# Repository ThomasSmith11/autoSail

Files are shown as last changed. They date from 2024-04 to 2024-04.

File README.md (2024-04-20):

# Autonomous Sailing System

## Overview
This project is aimed at developing an autonomous sailboat navigation system using Arduino and Python. The system enables the boat to navigate along a path of set waypoints autonomously.  Those waypoints can be selected graphically with a python app and uploaded to the vessel prior to launch.

## Components I Used
- **RC Laser**: https://rclaser.org/
  
- **Sail Winch Servo**: [https://www.amazon.com/Hitec-RCD-33785S-HS-785HB-Winch](https://www.amazon.com/Hitec-RCD-33785S-HS-785HB-Winch/dp/B000BOGI7E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)

- **Wind Direction Sensor**: [https://www.amazon.com/Direction-Sensor-Supply-Voltage-Output](https://www.amazon.com/Direction-Sensor-Supply-Voltage-Output/dp/B07GP154HP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)

- **GPS Sensor**: [https://www.amazon.com/Navigation-Positioning-Microcontroller-Compatible-Sensitivity](https://www.amazon.com/Navigation-Positioning-Microcontroller-Compatible-Sensitivity/dp/B0B31NRSD2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)

## Dependencies
- **Arduino IDE**: Required to upload the Arduino code to the microcontroller onboard the boat.
  
- **Python**: The Python application requires Python installed on the user's system. It also depends on several libraries present in Coordinate_Plotter/requirements.txt.

## Installation
1. Clone the repository to your local machine.
`git clone https://github.com/ThomasSmith11/autoSail.git`

2. Upload the Arduino code (`autoSail.ino`) to your Arduino board using the Arduino IDE.

3. Install the required Python dependencies.
`pip install Coordinate_Plotter/requirements.txt`

## Usage
1. Replace sail winch servo with purchased one, and install 3d printed wind direction sensor mount (found [here](Supplementary_Files)) on the bow of the boat.

2. Connect the Arduino board to your boat's hardware using the wiring diagram [here](Supplementary_Files/autoSailWiring.png).

3. Ensure that the boat is powered on.

4. Launch the Python application by running `python3 Coordinate_Plotter/gpsPlotter.py` and connect the arduino via USB.

5. Follow the on-screen instructions to select waypoints and send them to the boat.

6. Launch the boat, navigate to a safe location, then switch from manual control to autonomous control by pushing the left stick all the way to the right. You may regain manual control at any time by pushing the stick all the way to the left.

## License
This project is licensed under the MIT [License](LICENSE)

## Acknowledgments
- Special thanks to [@paulienov](https://github.com/paulienov) for helping design, troubleshoot, and debug the whole system as well as for printing the sensor mount.

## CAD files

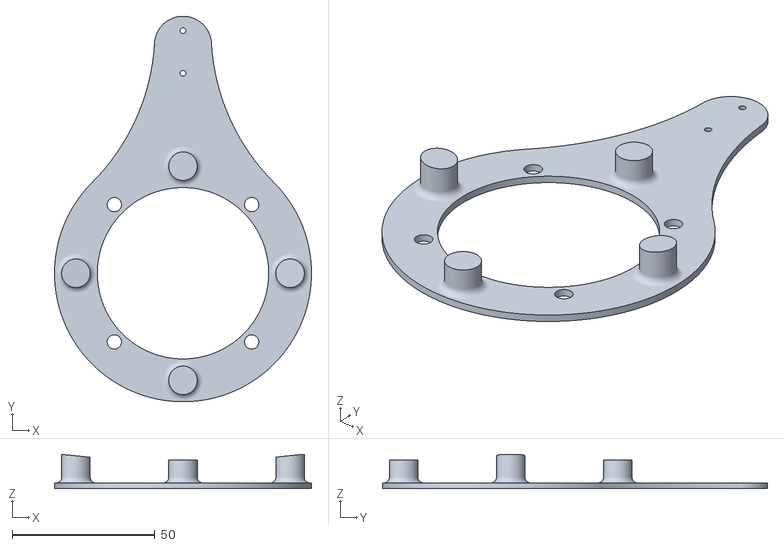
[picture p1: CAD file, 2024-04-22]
Supplementary_Files/RCLaserWindSensorMount_V3.stl
90.0 x 135.0 x 12.0

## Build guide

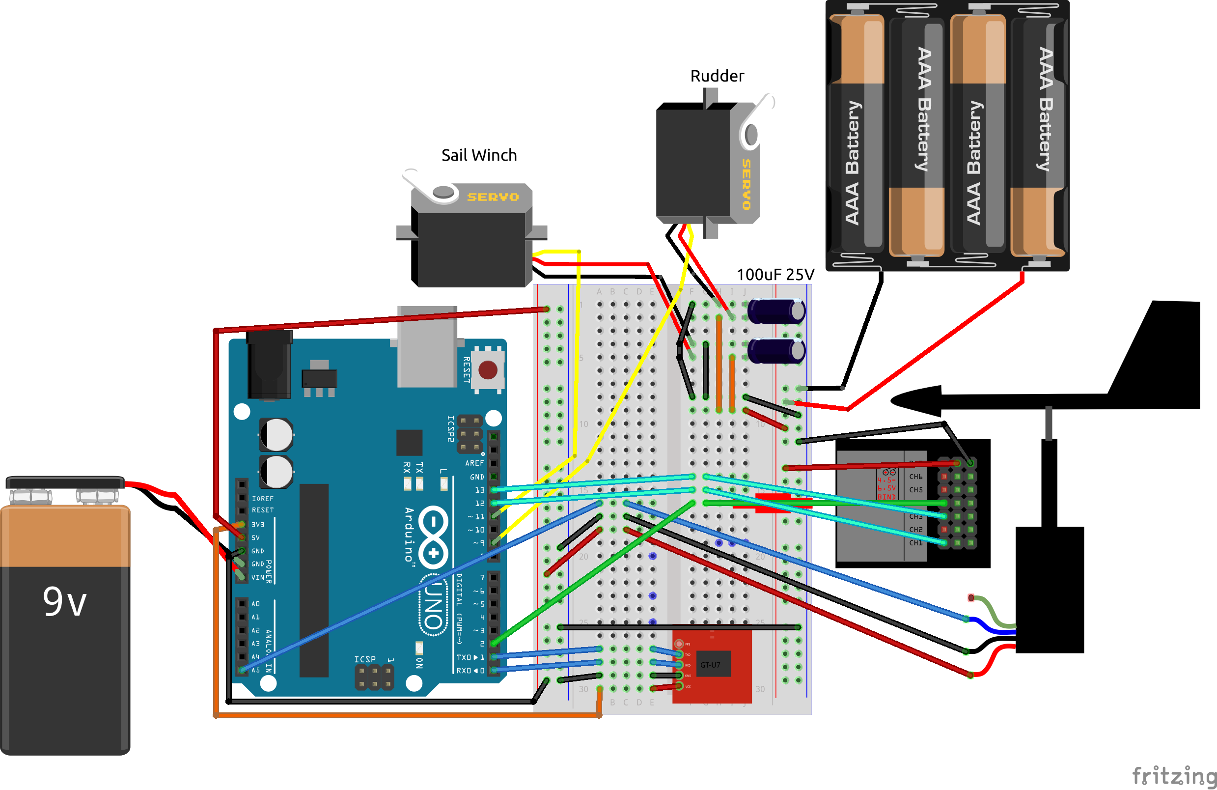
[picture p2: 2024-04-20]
Supplementary_Files/autoSailWiring.png

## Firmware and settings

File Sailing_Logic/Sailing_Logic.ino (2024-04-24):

#include <Servo.h>
#include <TinyGPS++.h>
#include <SoftwareSerial.h>

struct GPSCoordinate {
  float latitude;
  float longitude;
};

static const int controlPin = 2;
static const int gpsControlPin = 4;
static const int rudderOutputPin = 9;
static const int mainsheetOutputPin = 11;
static const int rudderPin = 12;
static const int mainsheetPin = 13;
static const int windSensorPin = A5;
static const uint32_t GPSBaud = 9600;
unsigned long time = 1400;

unsigned long waveStart;
unsigned long waveEnd;



Servo rudder;
Servo mainsheet;
TinyGPSPlus gps;


int prevIndex, destIndex;
GPSCoordinate prevCoords, currCoords, destCoords;


// Sensor inputs
int windSensorValue, mainsheetValue, rudderValue;


int windDirection;
int mainsheetTrim;
int rudderPosition;
float destHeading;
int currentHeading;
int targHeading;
float velocity;
float distanceOffLine;

char inData[26];
int numCoords = 0;
GPSCoordinate coordinates[32];


volatile bool manualControl = 1;
bool temp;
//May need to be switched


void setup() {
  Serial.begin(115200);
  Serial.println("Ready\n");
  while (true) {
    int index = 0;
    while (true) {
      if (Serial.available() > 0) {
        char c = Serial.read();
        if (c == '\n') {
          inData[index++] = '\0';
          break;
        } else {
          inData[index++] = c;
        }
      }
    }
    
    if (strcmp(inData, "␄") == 0) {
      break;
    }
    
    coordinates[numCoords++] = parseCoordinateString(inData);
  }
  attachInterrupt(digitalPinToInterrupt(controlPin), handleInterrupt, CHANGE);
  //audible ten second countdown before turning on gps and beginning loop
  for (int i = 0; i<10; i++) {
    blockingTone(7, 2000, 500);
    blockingTone(7, 0, 500);
  }
  Serial.begin(GPSBaud);
  pinMode(gpsControlPin, OUTPUT);
  digitalWrite(gpsControlPin, HIGH); // turn gps on
  pinMode(controlPin, INPUT);
  pinMode(rudderPin, INPUT);
  pinMode(mainsheetPin, INPUT);
  rudder.attach(rudderOutputPin);
  mainsheet.attach(mainsheetOutputPin);
}


void loop() {
  if (manualControl) {
    mainsheetValue = pulseIn(mainsheetPin, HIGH);
    rudderValue = pulseIn(rudderPin, HIGH);
    mainsheet.writeMicroseconds(mainsheetValue);
    rudder.writeMicroseconds(rudderValue);
  }
  else {
    finishedWaypoints:
    if (destIndex >= numCoords) {
      rudder.writeMicroseconds(1750);
    }
    while (Serial.available() > 0)
      if (gps.encode(Serial.read()))
        processGPS();

    if (prevIndex == NULL) {
      prevIndex = -1;
      destIndex = 0;
      prevCoords = currCoords;
      destCoords = coordinates[destIndex];
    }

    if (TinyGPSPlus::distanceBetween(currCoords.latitude, currCoords.longitude, destCoords.latitude, destCoords.longitude) < 3) {
      prevIndex++;
      destIndex++;
      if (destIndex >= numCoords) {
        goto finishedWaypoints;
      }
      destCoords = coordinates[destIndex];
      prevCoords = coordinates[prevIndex];
    }

    windSensorValue = analogRead(windSensorPin);
    Serial.println(windSensorValue);
    windDirection = map(windSensorValue, 0,1006, 0, 359);
    Serial.println(windDirection);
    mainsheetTrim = calculateSailAngle(windDirection);
    mainsheet.writeMicroseconds(mainsheetTrim);

    float destHeading = TinyGPSPlus::courseTo(currCoords.latitude, currCoords.longitude, prevCoords.latitude, prevCoords.longitude);

    distanceOffLine = calculateDistanceOffLine(destHeading, currCoords, prevCoords);
    bool toRightOfLine = determineSideofLine(destCoords, currCoords, prevCoords);
    targHeading = calculateTargetHeading(destHeading, currentHeading, windDirection, distanceOffLine, toRightOfLine);
    rudderPosition = calculateRudderPosition(currentHeading, targHeading);
    rudder.writeMicroseconds(rudderPosition);
  }
}


GPSCoordinate parseCoordinateString(char* gpsString) {
  GPSCoordinate coord;
  char *lat_str = strtok(gpsString, ",");
  char *lon_str = strtok(NULL, ",");
  if (lat_str != NULL && lon_str != NULL) {
    float lat = atof(lat_str);
    float lon = atof(lon_str);
    coord = {lat, lon};
  }
  return coord;
}


int calculateSailAngle(int windDirection) {
  int sailAngle;
  windDirection -= 180;
  windDirection = abs(windDirection);
  if (windDirection < 45) {
    sailAngle = 1750;
  }
  else {
    sailAngle = map(windDirection, 45, 180, 1750, 1150);
  }
  return sailAngle;
}


void processGPS() {
  if (gps.location.isValid())
  {
    currCoords.latitude = gps.location.lat();
    currCoords.longitude = gps.location.lng();
    currentHeading = int(gps.course.deg()+.5);
    // velocity = gps.speed.knots();
  }
}

void handleInterrupt(){
  int value = digitalRead(controlPin);
  if (value == 1) {
    waveStart = micros();
  }
  else {
    waveEnd = micros();
    time = waveEnd - waveStart;
  }
  if(time<1250){
    manualControl = 1;
  }
  if(time>1800){
    manualControl = 0;
  }
}


float calculateDistanceOffLine(float destHeading, GPSCoordinate current, GPSCoordinate previous) {
  float currLat = current.latitude;
  float currLon = current.longitude;
  float prevLat = previous.latitude;
  float prevLon = previous.longitude;

  float headingFromPrevToCurrent = TinyGPSPlus::courseTo(prevLat, prevLon, currLat, currLon);
  float distanceFromPrevToCurrent = TinyGPSPlus::distanceBetween(prevLat, prevLon, currLat, currLon);
  float theta = radians(headingFromPrevToCurrent - destHeading);
  return distanceFromPrevToCurrent * sin(theta);
}


bool determineSideofLine(GPSCoordinate destination, GPSCoordinate current, GPSCoordinate previous) {
  float Ax = destination.latitude - previous.latitude;
  float Ay = destination.longitude - previous.longitude;
  float Bx = current.latitude - previous.latitude;
  float By = current.longitude - previous.longitude;

  float crossProduct = Ax * By - Bx * Ay;

  if (crossProduct > 0) {
    return 1;
  } else {
    return 0;
  }
}


int calculateRudderPosition(int currentHeading, int targHeading) {
  int rudderScale;
  
  int clockwiseDiff = (targHeading - currentHeading + 360) % 360;
  int counterclockwiseDiff = (currentHeading - targHeading + 360) % 360;
  if (clockwiseDiff < counterclockwiseDiff) {
      rudderScale = calcRudderScale(abs(targHeading-currentHeading));
  } else {
      rudderScale = calcRudderScale(abs(targHeading-currentHeading))*-1;
  }

  return rudderScale+1515;
}


int calcRudderScale(int headingDiff) {

// change rudder scale in 8 degree increments, such that above ~40 degrees off course we get maximum steering,
// then smoother steering as we approach the correct course.  Max rudder scale should be 6, min -6

  if (headingDiff >= 60) {
    return 400;
  }
  else {
    return map(headingDiff, 0, 59, 0, 400);
  }
}


int calculateTargetHeading(float destHeading, int currentHeading, int windDirection, float distanceAway, bool toRightOfLine) {
  int actualWindDirection = (windDirection+currentHeading)%360;
  if (abs(actualWindDirection-destHeading) > 40) {
    return int(destHeading+.5); //round destHeading to nearest whole number
  }
  else {
    if (distanceAway < 3) {
      int clockwiseDiff = (actualWindDirection - currentHeading + 360) % 360;
      int counterclockwiseDiff = (currentHeading - actualWindDirection + 360) % 360;
      bool starboard = (clockwiseDiff<counterclockwiseDiff);
      if (starboard) {
        return (actualWindDirection + 320) % 360;
      }
      else {
        return (actualWindDirection + 40) % 360;
      }
    }
    else {
      if (toRightOfLine) {
        return (actualWindDirection + 320) % 360;
      }
      else {
        return (actualWindDirection + 40) % 360;
      }
    }
  }
}


void blockingTone(uint8_t pin, unsigned int frequency, unsigned long duration) {
    pinMode(pin, OUTPUT);
    unsigned long startTime = micros();

    while (micros() - startTime < duration * 1000) {
        unsigned long currentTime = micros() - startTime;
        if (currentTime % (1000000 / frequency) < (1000000 / (2 * frequency))) {
            digitalWrite(pin, HIGH);
        } else {
            digitalWrite(pin, LOW);
        }
    }

    digitalWrite(pin, LOW);
}

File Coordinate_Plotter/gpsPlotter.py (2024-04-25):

import time
import serial
import tkinter
import customtkinter
import serial.tools.list_ports
from tkintermapview import TkinterMapView
from tkintermapview.canvas_position_marker import CanvasPositionMarker

customtkinter.set_default_color_theme("dark-blue")

class CustomWaypointMarker(CanvasPositionMarker):
    def __init__(self, *args, **kwargs):
        super().__init__(*args, **kwargs)
        self.text_color = "#C5542D"

class CustomMapView(TkinterMapView):
    
    def __init__(self, app, *args, **kwargs):
        super().__init__(*args, **kwargs)
        self.app = app
        self.tile_server = "https://mt0.google.com/vt/lyrs=s&hl=en&x={x}&y={y}&z={z}&s=Ga"
    
    def mouse_right_click(self, event):
        coordinate_mouse_pos = self.convert_canvas_coords_to_decimal_coords(event.x, event.y)

        def click_coordinates_event():
            try:
                self.set_marker(coordinate_mouse_pos[0], coordinate_mouse_pos[1], text=(str(len(app.waypointList)+1)))
                app.update_waypoints_listbox()

            except Exception as err:
                tkinter.messagebox.showinfo(title="", message="Error adding waypoint to course: \n" + str(err))

        m = tkinter.Menu(self, tearoff=0)
        m.add_command(label=f"Add Waypoint", command=click_coordinates_event)

        m.tk_popup(event.x_root, event.y_root)
    
    def set_marker(self, deg_x: float, deg_y: float, text: str = None, **kwargs) -> CustomWaypointMarker:
        marker = CustomWaypointMarker(self, (deg_x, deg_y), text=text, **kwargs)
        marker.draw()
        self.canvas_marker_list.append(marker)
        return marker


class App(customtkinter.CTk):

    APP_NAME = "AutoSail GPS Plotter"
    WIDTH = 1400
    HEIGHT = 800

    def __init__(self, *args, **kwargs):
        super().__init__(*args, **kwargs)
        customtkinter.set_appearance_mode("dark")
        self.title(App.APP_NAME)
        self.geometry(str(App.WIDTH) + "x" + str(App.HEIGHT))
        self.minsize(App.WIDTH, App.HEIGHT)

        self.protocol("WM_DELETE_WINDOW", self.on_closing)
        self.bind("<Control-q>", self.on_closing)
        self.bind("<Control-w>", self.on_closing)

        # ============ create two CTkFrames ============

        self.grid_columnconfigure(0, weight=0)
        self.grid_columnconfigure(1, weight=1)
        self.grid_rowconfigure(0, weight=1)

        self.infoFrame = customtkinter.CTkFrame(master=self, width=App.WIDTH/4, corner_radius=0, fg_color=None)
        self.infoFrame.grid(row=0, column=0, padx=0, pady=0, sticky="nsew")

        self.mapFrame = customtkinter.CTkFrame(master=self, corner_radius=0)
        self.mapFrame.grid(row=0, column=1, rowspan=1, pady=(0, 20), padx=(0, 20), sticky="nsew")

        # ============ info frame ============

        self.infoFrame.grid_rowconfigure(3, weight=1)

        self.clearWaypointsButton = customtkinter.CTkButton(master=self.infoFrame,
                                                text="Clear Waypoints",
                                                command=self.clearWaypoints)
        self.clearWaypointsButton.grid(pady=(20, 20), padx=(20, 20), row=5, column=0)

        self.removeRecentWaypointButton = customtkinter.CTkButton(master=self.infoFrame,
                                                text="Remove Latest Waypoint",
                                                command=self.removeRecentWaypoint)
        self.removeRecentWaypointButton.grid(pady=(0, 0), padx=(20, 20), row=4, column=0)

        self.waypoints_listbox = tkinter.Listbox(self.infoFrame, fg="white", bg="black")

        self.waypoints_listbox.grid(row=3, column=0, padx=(20, 20), pady=(20, 20), sticky="nsew")

        self.sendWaypointsButton = customtkinter.CTkButton(master=self.infoFrame,
                                                text="Send Waypoints to Vessel",
                                                command=self.sendWaypoints)

        self.sendWaypointsButton.grid(pady=(20, 0), padx=(20, 20), row=2, column=0)
        self.serial_ports = ["No port selected"]
        self.port_option_menu = customtkinter.CTkOptionMenu(self.infoFrame, values=self.serial_ports, command=self.change_port)
        self.get_serial_ports(self.port_option_menu)
        self.serial_port = self.serial_ports[-1]
        self.serial_port_label = customtkinter.CTkLabel(self.infoFrame, text="Port:")
        self.serial_port_label.grid(pady=(20, 0), padx=(30, 0), row=1, column=0, sticky="w")
        self.port_option_menu.grid(row=1, column=0, padx=(0, 30), pady=(20, 0), sticky="e")

        # ============ map frame ============

        self.mapFrame.grid_rowconfigure(1, weight=1)
        self.mapFrame.grid_rowconfigure(0, weight=0)
        self.mapFrame.grid_columnconfigure(0, weight=1)
        self.mapFrame.grid_columnconfigure(1, weight=0)
        self.mapFrame.grid_columnconfigure(2, weight=1)

        self.map_widget = CustomMapView(self, self.mapFrame, corner_radius=0)
        self.waypointList = self.map_widget.canvas_marker_list
        self.map_widget.grid(row=1, rowspan=1, column=0, columnspan=3, sticky="nswe", padx=(0, 0), pady=(0, 0))
        self.entry = customtkinter.CTkEntry(master=self.mapFrame,
                                            placeholder_text="Search Google Maps")
        self.entry.grid(row=0, column=0, sticky="we", padx=(12, 0), pady=12)
        self.entry.bind("<Return>", self.search_event)

        self.searchButton = customtkinter.CTkButton(master=self.mapFrame, text="Search", width=90, command=self.search_event)
        self.searchButton.grid(row=0, column=1, sticky="w", padx=(12, 0), pady=12)

        self.instruction = customtkinter.CTkLabel(self.mapFrame, text="Right click to place waypoint")
        self.instruction.grid(row=0, column=2, padx=(10, 20), pady=12, sticky="ew")

        self.map_widget.set_address("Wilmington, NC")

    def get_serial_ports(self, port_option_menu):
        ports = [port.device for port in serial.tools.list_ports.comports()]
        ports.append("No port selected")
        self.serial_ports = ports
        port_option_menu.configure(values=self.serial_ports)
        self.after(1000, self.get_serial_ports, port_option_menu)

    def change_port(self, port):
        self.serial_port = port

    def search_event(self, event=None):
        self.map_widget.set_address(self.entry.get())

    def update_waypoints_listbox(self):
        self.waypoints_listbox.delete(0, tkinter.END)

        for i, waypoint in enumerate(self.waypointList, start=1):
            lat, lon = waypoint.position
            lat_str = "{:.5f}".format(lat)
            lon_str = "{:.5f}".format(lon)
            curWidth = 2*len(str(i)) + len(lat_str)+len(lon_str)
            padWidth = 23 - curWidth
            space = " "
            self.waypoints_listbox.insert(tkinter.END, f"{i}:{space*padWidth}{lat_str}, {lon_str}")
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

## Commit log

2024-04-11 very rough idea of steering
2024-04-16 change wait 5 seconds to wait for arduino to signal ready, implement updating port list
2024-04-16 added serial recv to arduino, changed python baudrate to match
2024-04-16 fix some copy paste errors
    [autoSail.ino]
2024-04-16 disable board reset after serial disconnect
    [gpsPlotter.py]
2024-04-20 Added manual/programatic control switch capabilities
2024-04-20 add wiring diagram and wind sensor mount stl files
    [RCLaserWindSensorMount.stl]
2024-04-21 update stl to accomadate bow convexity
    [RCLaserWindSensorMount.stl, RCLaserWindSensorMount_V2.stl]
2024-04-22 add angle to outside supports
    [RCLaserWindSensorMount_V2.stl, RCLaserWindSensorMount_V3.stl]
2024-04-24 transition to hardware serial to avoid interrupt issues with software serial interfering with pulseIn and timing the control pin
    [Sailing_Logic.ino]
2024-04-25 change software solution for reset disable to hardware solution
    [gpsPlotter.py]
